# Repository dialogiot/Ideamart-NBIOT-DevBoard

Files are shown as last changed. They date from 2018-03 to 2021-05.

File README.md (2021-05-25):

### About the Board

The board is developed based on the [SIM7000C](http://www.simcomm2m.com/En/module/detail.aspx?id=167) and [SIM7000E](http://www.simcomm2m.com/En/module/detail.aspx?id=168) Modules as well as the Microcontroller ATMega 328 based on the most popular Arduino UNO PIN layout. Therefore this board is compatible with any shield that is compatible with the Arduino UNO

### Distribution
Any one can destribute or modify this deign. but originated souce should be published

### NB-IOT /GPS sample and SDK
[https://github.com/dialogiot/Dialog_NB-IOT_CAT-M](https://github.com/dialogiot/Dialog_NB-IOT_CAT-M)

#### Drivers

Download the [USB Drivers](https://github.com/botletics/SIM7000-LTE-Shield/wiki/SIM7000-USB-Drivers)
Note: Windows 10 users should use the Windows 8 Drivers



[View Image](https://idealab.ideamart.io/NBIOT-Dev-Board/img/features/board-diagram.jpg)

|No|PIN |Description|
|---|---|---|
| 1 | USB Port | Programing USB port for ATMEL Chip - PC driver may be required. Use Arduino USB cable or USB printer wire to connect with PC |
| 2 | FTDI | FTDI USB to Serial Converter FT232RL chip |
| 3 | LED2 | User programable LED |
| 4 | PIN Headers | Programable PIN headers to connect with micro controller. (Diagram 2 for more details) |
| 5 | Level Shifter | 1.8V to 5V voltage level shifter |
| 6 | SIM7000 | SIM7000 NB-IOT/eMTC/GSM/LTE Modem and GNSS Receiver |
| 7 | RF Antenna | RF mobile network antenna port for SIM7000 (u.fL) |
| 8 | GPS Antenna | GPS signal antenna port for SIM7000 (u.fL) |
| 9 | PPTC | PPTC resettable fuse for USB input over current protection (max 500mA) |
| 10 | DC Input | 2.1mm 7-12V DC power input |
| 11 | RESET | ATMEGA328P micro controller reset button |
| 12 | 3.3V Regulator | Lm1117 3.3V low dropout linear regulator (max 800ma)|
| 13 | 5V Regulator | LM1117 5V low dropout linear regulator (max 800mA) |
| 14 | PIN Headers | Programable PIN headers to connect with micro controller.(Diagram 2 for more details) |
| 15 | ATMEGA328P | ATMEGA328P micro controller |
| 16 | Power LED | Power indicator LED |
| 17 | ICSP Header | ICSP Header for Arduino programming |
| 18 | Modem Reset | SIM7000 modem hardware reset button |
| 19 | STAT LED | SIM7000 modem STAT LED indicator |
| 20 | Modem USB | SIM7000 modem USB port - firmware upgrade - Modem debug |
| 21 | PWR KEY | SIM7000 modem power key - Press 1.5sec to power up/down |
| 22 | Net Light | Power indicator LED |

## 2 What you Should know about the board

- ATMEGA328P µCU with FTDI USB to serial converter
- Same pinout as Arduino UNO
- Compatible with any Arduino UNO shield
- Programable with Arduino IDE
- NB-IoT/GSM/LTE/eMTC enabled SIM7000C/SIM7000E module onboard
- Separate USB interface for SIM7000 module
- GNSS (GPS,GLONASS and BeiDou/Compass, Galileo, QZSS)enabled 

> Separate USB interface can only be used for SIM7000 debug and firmware upgrades

- SIM7000C FDD-LTE B1/B3/B5/B8
- SIM7000E Tri-Band FDD-LTE B3/B8/B20/B28
- GSM/GPRS/EDGE 900/1800 MHz
- GNSS (GPS,GLONASS and BeiDou/Compass, Galileo, QZSS)
- LTE CAT-M1(eMTC) Uplink up to 375kbps, Downlink up to 300kbps
- NB-IoT Uplink up to 66kbps, Downlink up to 34kbps
- EDGE Class Uplink up to 236.8Kbps, Downlink up to 236.8Kbps
- GPRS Uplink up to 85.6Kbps, Downlink up to 85.6Kbps

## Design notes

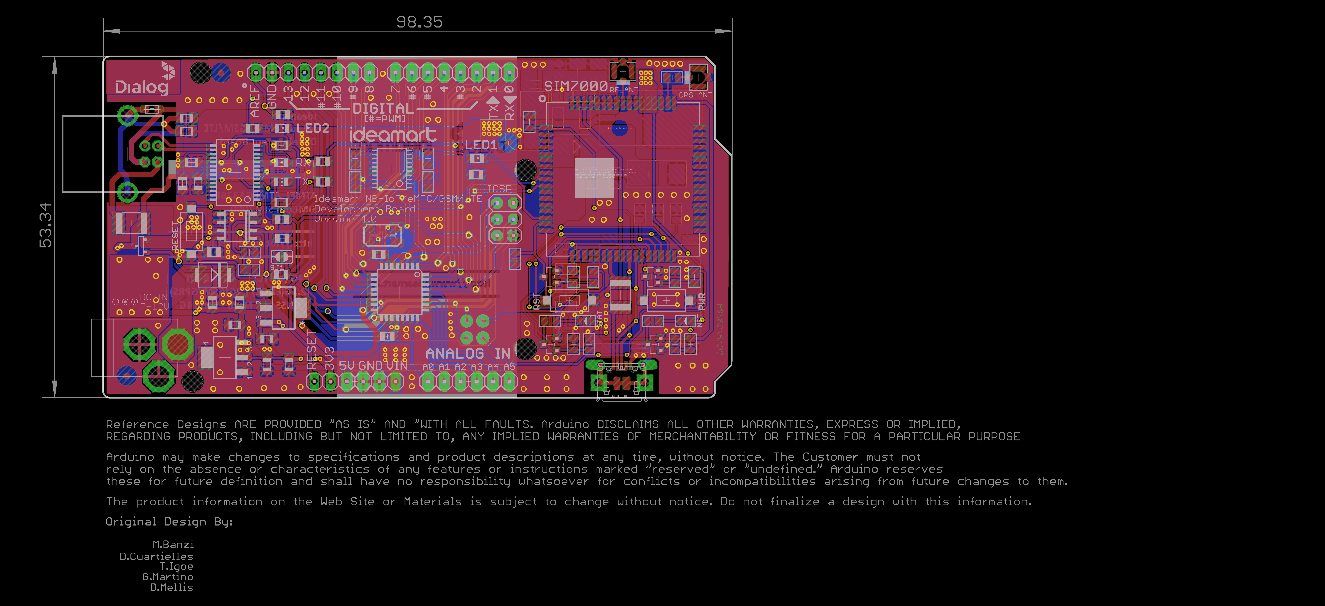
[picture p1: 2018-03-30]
Board-Images/Ideamart_NB-IoT_Dev_Board-Schematic-PCB_layout.png

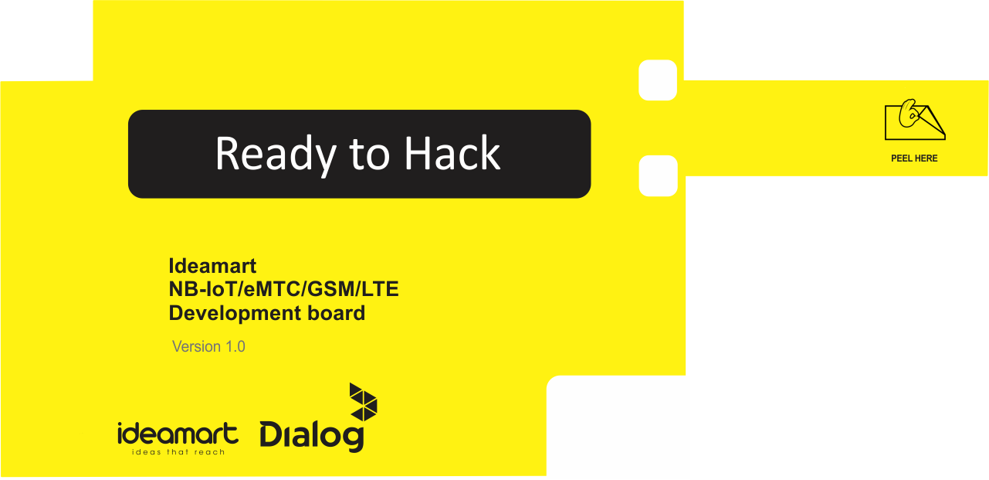
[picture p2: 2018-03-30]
Other-Images/Peel.png

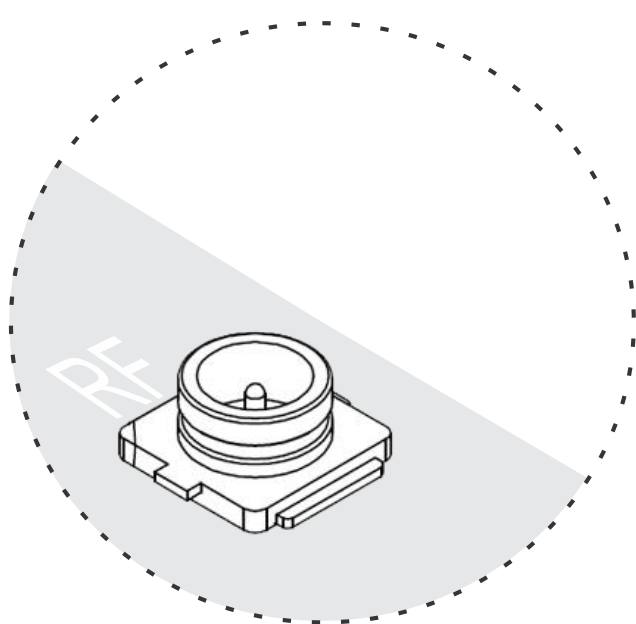
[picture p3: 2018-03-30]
Other-Images/Ant.png

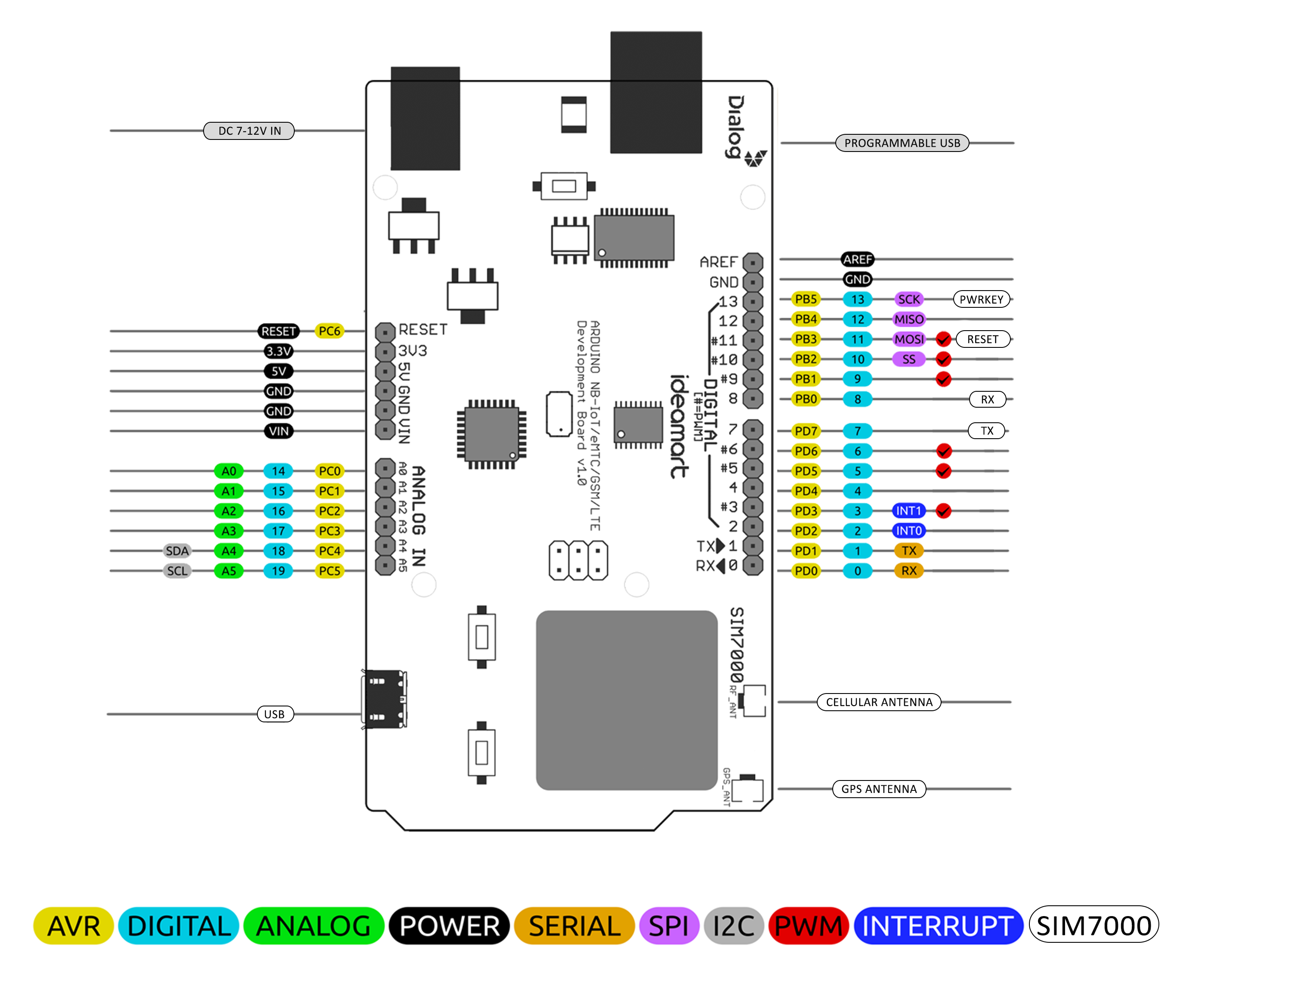
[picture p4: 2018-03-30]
Other-Images/PinOut.png

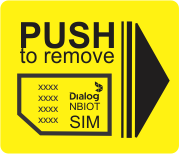
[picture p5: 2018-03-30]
Other-Images/Sim.png

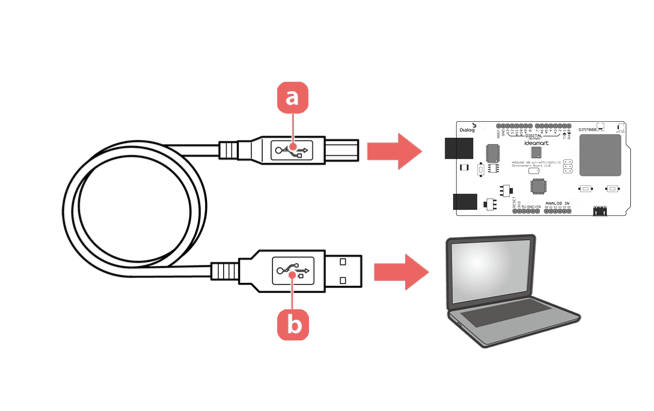
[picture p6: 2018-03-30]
Other-Images/Cable.png

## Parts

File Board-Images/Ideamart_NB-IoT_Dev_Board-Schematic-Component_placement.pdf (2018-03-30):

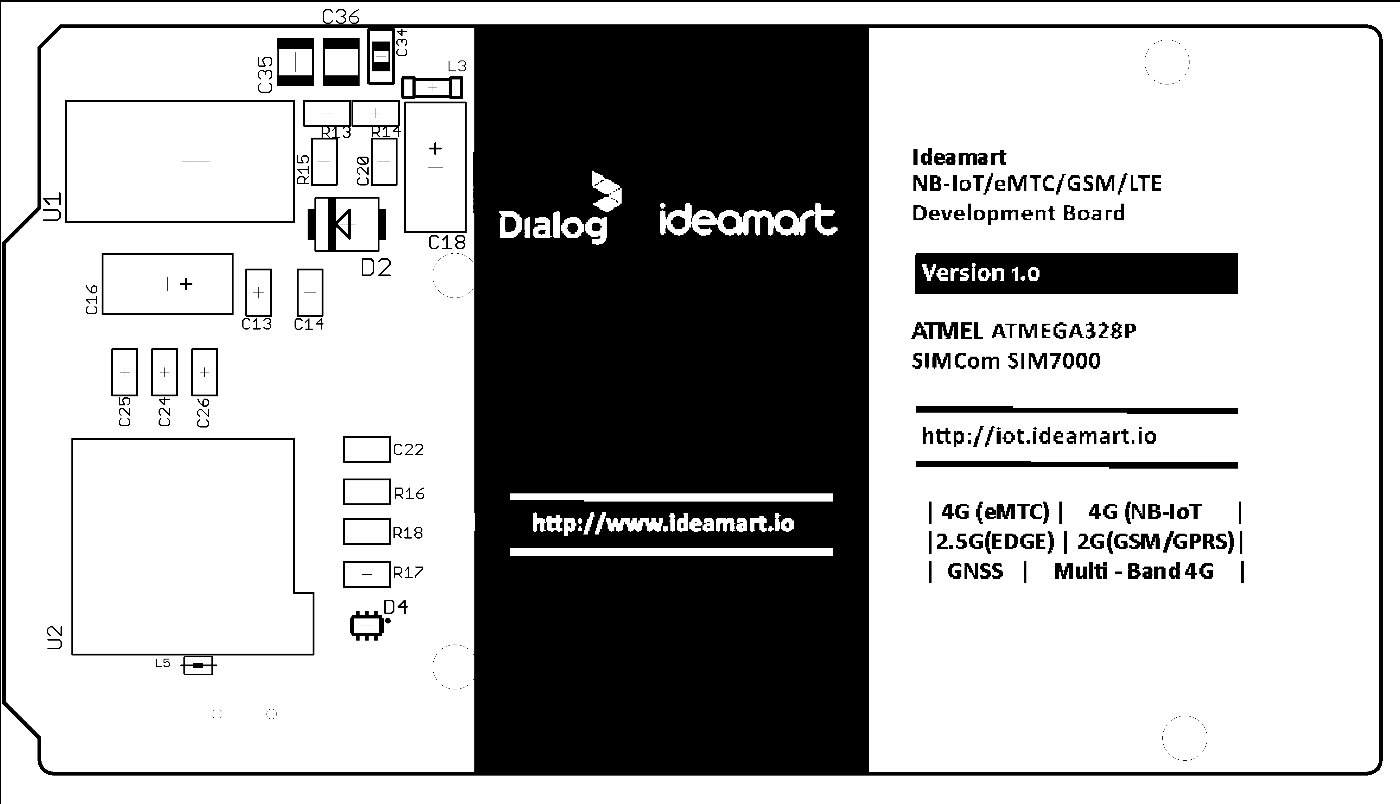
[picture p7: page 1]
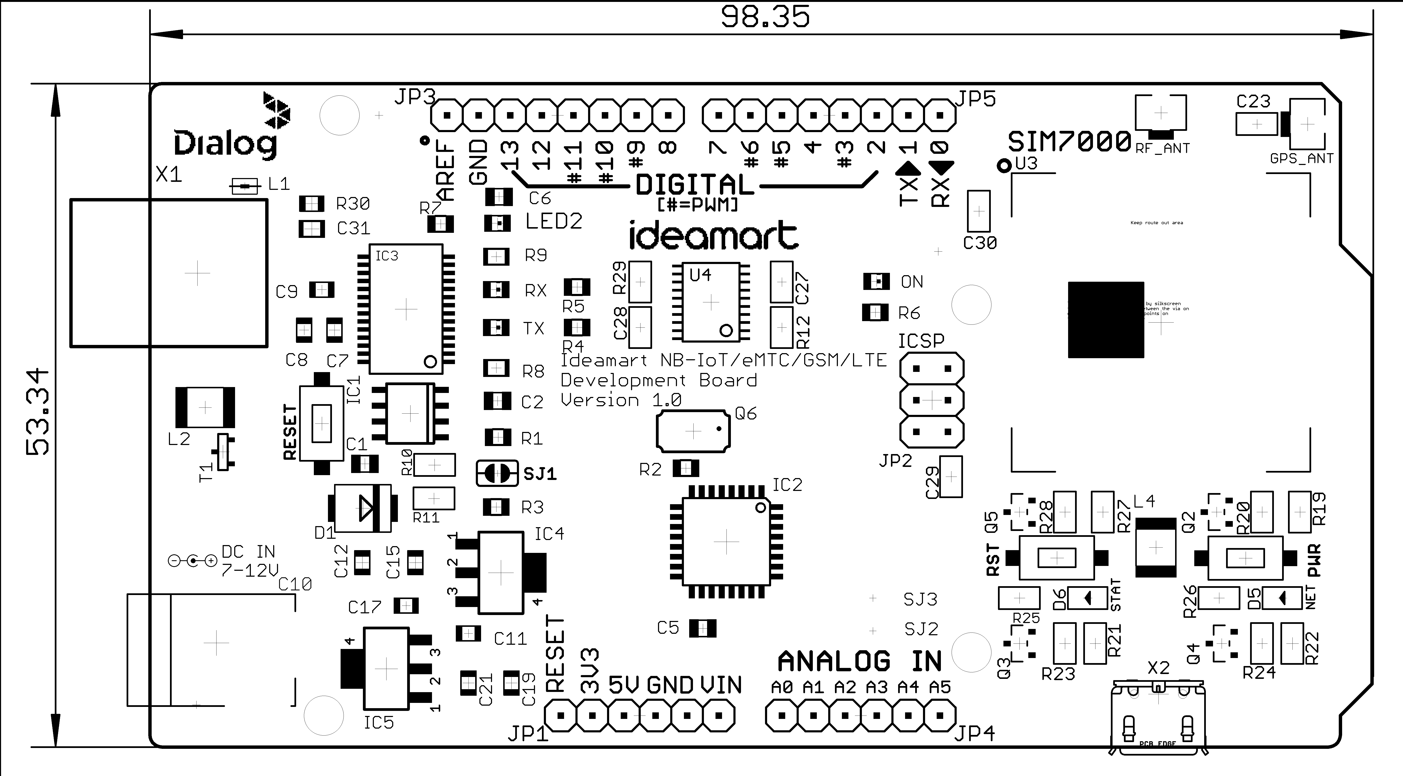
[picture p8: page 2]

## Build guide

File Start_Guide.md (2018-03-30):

## 1 Let's Start


- Insert Micro SIM to sim slot
- Connect GPS antenna to board

> NB-IOT / eMTC should available in your area

> Your SIM should allow to connect to NB-IOT network


- Connect your u.fL connector of GSM/LTE antenna to board
- Connect GPS antenna to board

## 2 Connect to the Computer

Connect Ideamart Board to the computer using USB cable



> You may need to install drivers for your computer.

> Download SDK and program with your faviorit Arduino IDE
SDK download from http://go.ideamart.io/NBIOTDevBoard

## 3 Board PIN out



[View Image](https://docs.iot.ideamart.io/images/nbiot/PinOut.png)

More Information/Sample and all you need info can find at
http://go.ideamart.io/NBIOTDevBoard

Dialog IOT Platform
http://portal.iot.ideamart.io

Dialog Smartlife app
http://go.ideamart.io/smartlife

### Microcontroller	ATmega328P

| | |
|-|-|
| Operating Voltage	| 5V |
| Input Voltage (recommended)	| 7-12V |
| Input Voltage (limit)	| 7-12V |
| Digital I/O Pins	| 14 (of which 6 provide PWM output) |
| PWM Digital I/O Pins	| 6 |
| Analog Input Pins	| 6 |
| DC Current per I/O Pin	| 20 mA |
| DC Current for 3.3V Pin	| 50 mA |
| Flash Memory	| 32 KB (ATmega328P) of which 0.5 KB used by bootloader |
| SRAM	| 2 KB (ATmega328P) |
| EEPROM	| 1 KB (ATmega328P) |
| Clock Speed	| 16 MHz |
| LED_BUILTIN	| 13 |
| Length	| 98.35 mm |
| Width	| 53.38 mm |

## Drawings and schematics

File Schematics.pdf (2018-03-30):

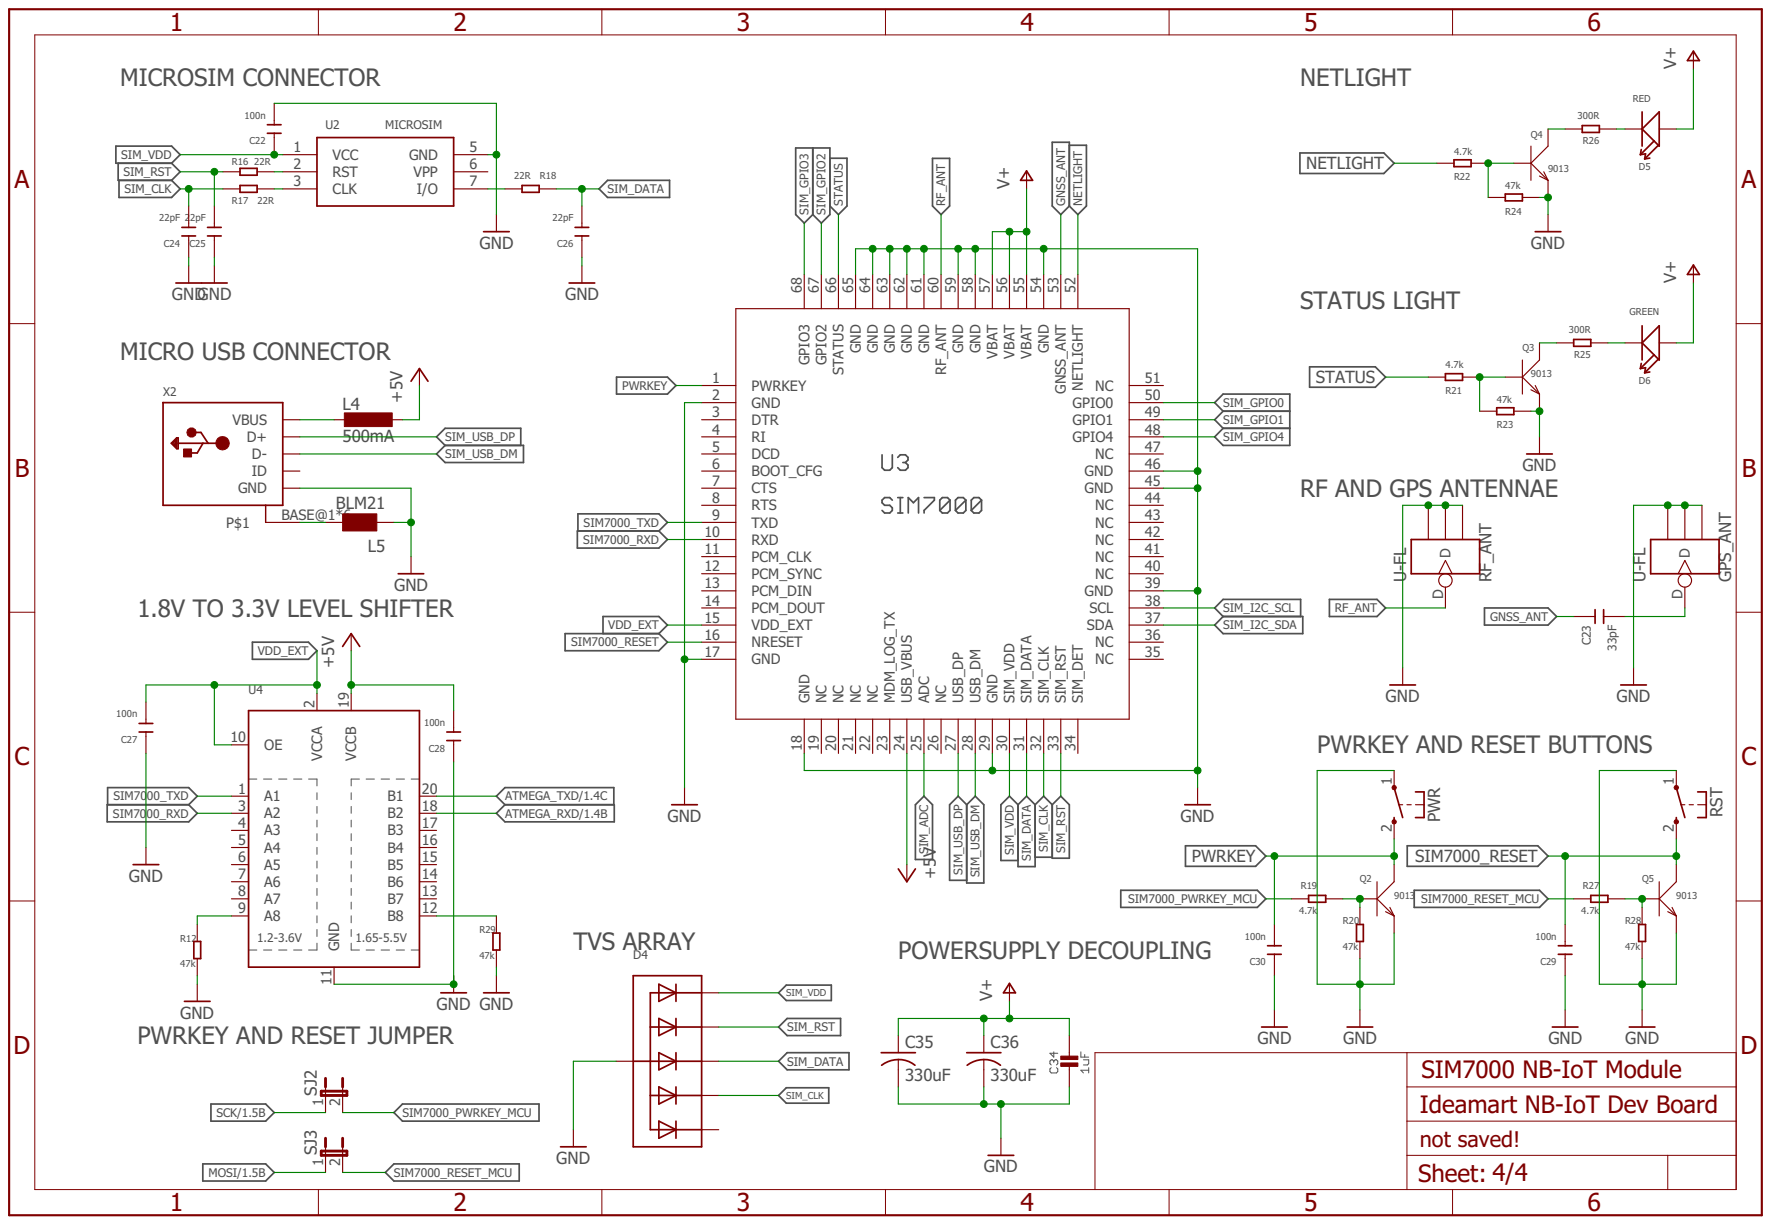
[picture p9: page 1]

RF AND GPS ANTENNAE

PWRKEY AND RESET BUTTONS

GND
PWRKEY AND RESET JUMPER

SIM7000 NB-IoT Module
Ideamart NB-IoT Dev Board

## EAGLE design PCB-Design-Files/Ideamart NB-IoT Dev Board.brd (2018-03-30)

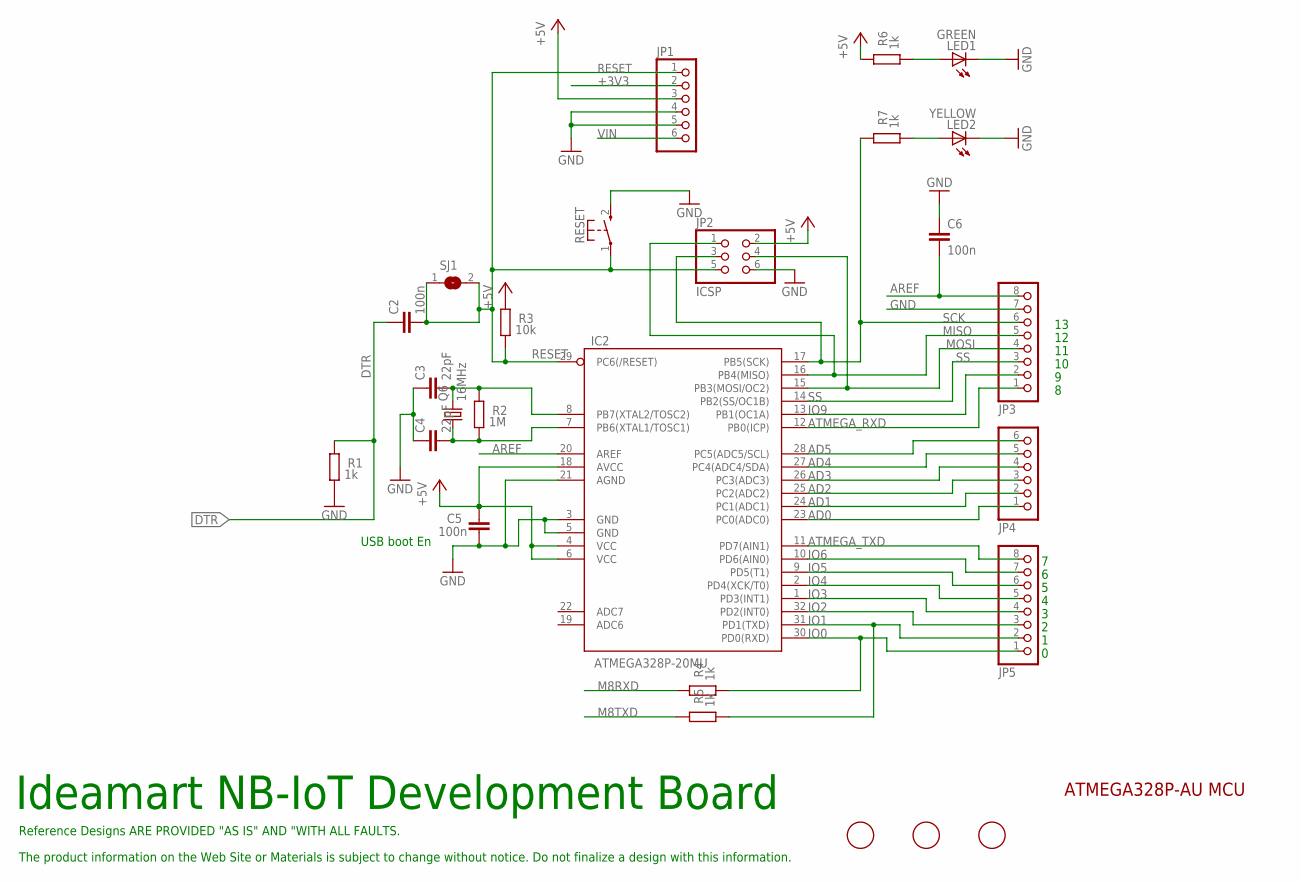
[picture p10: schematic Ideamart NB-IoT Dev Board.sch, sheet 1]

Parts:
C2, C5, C6: 100n; C0805
C3, C4: 22pF; C0805
IC2: ATMEGA328P-20MU; TQFP32-08
JP1, JP4: PINHD-1X6; 1X06
JP2: ICSP; 2X03
JP3, JP5: PINHD-1X8; 1X08
LED1: GREEN; CHIP-LED0805
LED2: YELLOW; CHIP-LED0805
M1, M2, M3: FIDUCIALMOUNT; FIDUCIA-MOUNT
Q6: 16MHz; CTS406
R1, R4, R5, R6, R7: 1k; R0805
R2: 1M; R0805
R3: 10k; R0805
RESET: KSS-2EG4430
SJ1: SJ

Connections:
+3V3: JP1.2; also elsewhere on the board
+5V: C5.2, IC2.4 (VCC), IC2.6 (VCC), IC2.18 (AVCC), JP1.3, JP2.2, R3.2, R6.2; also elsewhere on the board
AD0: IC2.23 (PC0(ADC0)), JP4.1
AD1: IC2.24 (PC1(ADC1)), JP4.2
AD2: IC2.25 (PC2(ADC2)), JP4.3
AD3: IC2.26 (PC3(ADC3)), JP4.4
AD4: IC2.27 (PC4(ADC4/SDA)), JP4.5
AD5: IC2.28 (PC5(ADC5/SCL)), JP4.6
AREF: C6.2, IC2.20 (AREF), JP3.8
ATMEGA_RXD: IC2.12 (PB0(ICP)), JP3.1; also elsewhere on the board
ATMEGA_TXD: IC2.11 (PD7(AIN1)), JP5.8; also elsewhere on the board
DTR: C2.1, R1.2; also elsewhere on the board
GND: C3.1, C4.1, C5.1, C6.1, IC2.3 (GND), IC2.5 (GND), IC2.21 (AGND), JP1.4, JP1.5, JP2.6, JP3.7, LED1.C, LED2.C, R1.1, RESET.2 (S); also elsewhere on the board
IO0: IC2.30 (PD0(RXD)), JP5.1, R4.1
IO1: IC2.31 (PD1(TXD)), JP5.2, R5.1
IO2: IC2.32 (PD2(INT0)), JP5.3
IO3: IC2.1 (PD3(INT1)), JP5.4
IO4: IC2.2 (PD4(XCK/T0)), JP5.5
IO5: IC2.9 (PD5(T1)), JP5.6
IO6: IC2.10 (PD6(AIN0)), JP5.7
IO9: IC2.13 (PB1(OC1A)), JP3.2
M8RXD: R4.2; also elsewhere on the board
M8TXD: R5.2; also elsewhere on the board
MISO: IC2.16 (PB4(MISO)), JP2.1, JP3.5
MOSI: IC2.15 (PB3(MOSI/OC2)), JP2.4, JP3.4; also elsewhere on the board
unnamed: LED2.A, R7.1
unnamed: LED1.A, R6.1
RESET: C2.2, IC2.29 (PC6(/RESET)), JP1.1, JP2.5, R3.1, RESET.1, SJ1.1, SJ1.2
SCK: IC2.17 (PB5(SCK)), JP2.3, JP3.6, R7.2; also elsewhere on the board
SS: IC2.14 (PB2(SS/OC1B)), JP3.3
VIN: JP1.6; also elsewhere on the board
XTAL1: C4.2, IC2.7 (PB6(XTAL1/TOSC1)), Q6.1, R2.1
XTAL2: C3.2, IC2.8 (PB7(XTAL2/TOSC2)), Q6.3 (2), R2.2

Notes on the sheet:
Ideamart NB-IoT Development Board
USB boot En
Reference Designs ARE PROVIDED "AS IS" AND "WITH ALL FAULTS.
The product information on the Web Site or Materials is subject to change without notice. Do not finalize a design with this information.
ATMEGA328P-AU MCU

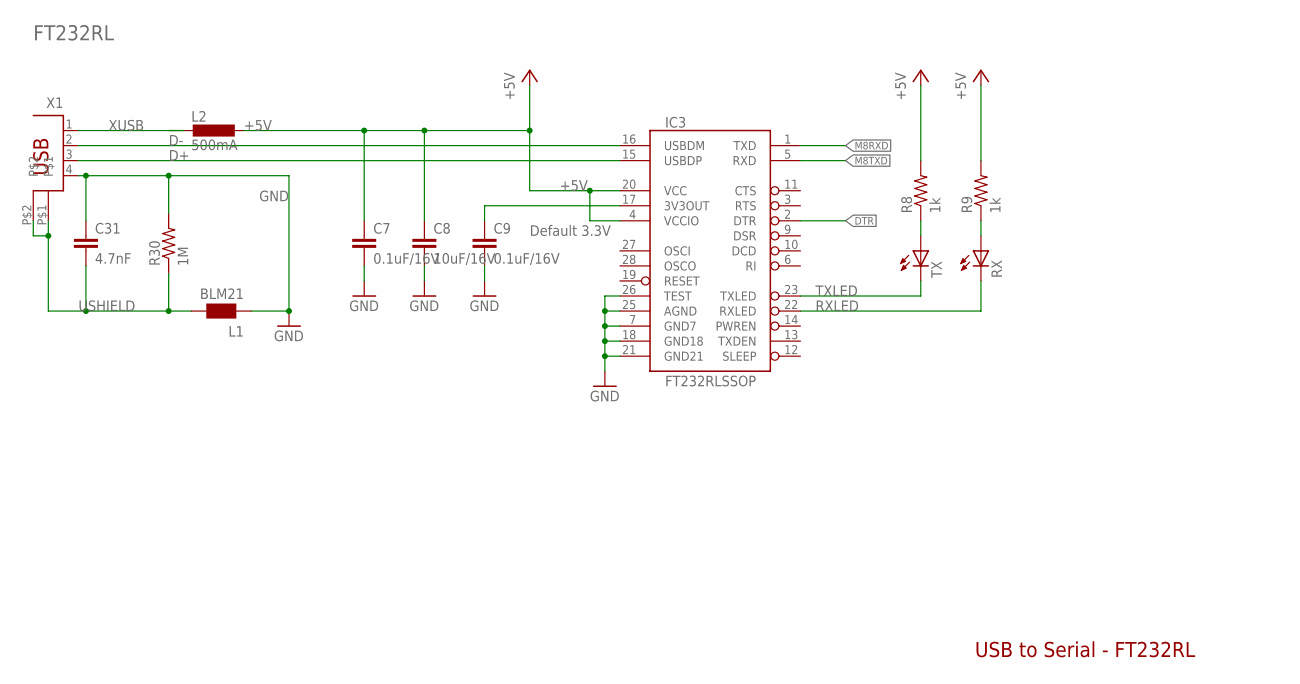
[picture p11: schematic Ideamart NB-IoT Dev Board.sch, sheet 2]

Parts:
C7, C9: 0.1uF/16V; C0805K
C8: 10uF/16V; C0805K
C31: 4.7nF; C0805K
IC3: FT232RLSSOP; SSOP28DB
L1: BLM21; 0805
L2: 500mA; L1812
R8, R9: 1k; M0805
R30: 1M; M0805
RX: LEDCHIP-LED0805; CHIP-LED0805
TX: LEDCHIP-LED0805; CHIP-LED0805
X1: PN61729

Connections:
+5V: C7.1, C8.1, IC3.4 (VCCIO), IC3.20 (VCC), L2.1, R8.2, R9.2; also elsewhere on the board
D+: IC3.15 (USBDP), X1.3
D-: IC3.16 (USBDM), X1.2
DTR: IC3.2 (DTR); also elsewhere on the board
GND: C7.2, C8.2, C9.2, C31.1, IC3.7 (GND7), IC3.18 (GND18), IC3.21 (GND21), IC3.25 (AGND), IC3.26 (TEST), L1.1, R30.2, X1.4; also elsewhere on the board
M8RXD: IC3.1 (TXD); also elsewhere on the board
M8TXD: IC3.5 (RXD); also elsewhere on the board
unnamed: C9.1, IC3.17 (3V3OUT)
unnamed: R8.1, TX.A
unnamed: R9.1, RX.A
RXLED: IC3.22 (RXLED), RX.C
TXLED: IC3.23 (TXLED), TX.C
USHIELD: C31.2, L1.2, R30.1, X1.P$1, X1.P$2
XUSB: L2.2, X1.1

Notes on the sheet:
Default 3.3V
USB to Serial - FT232RL
FT232RL

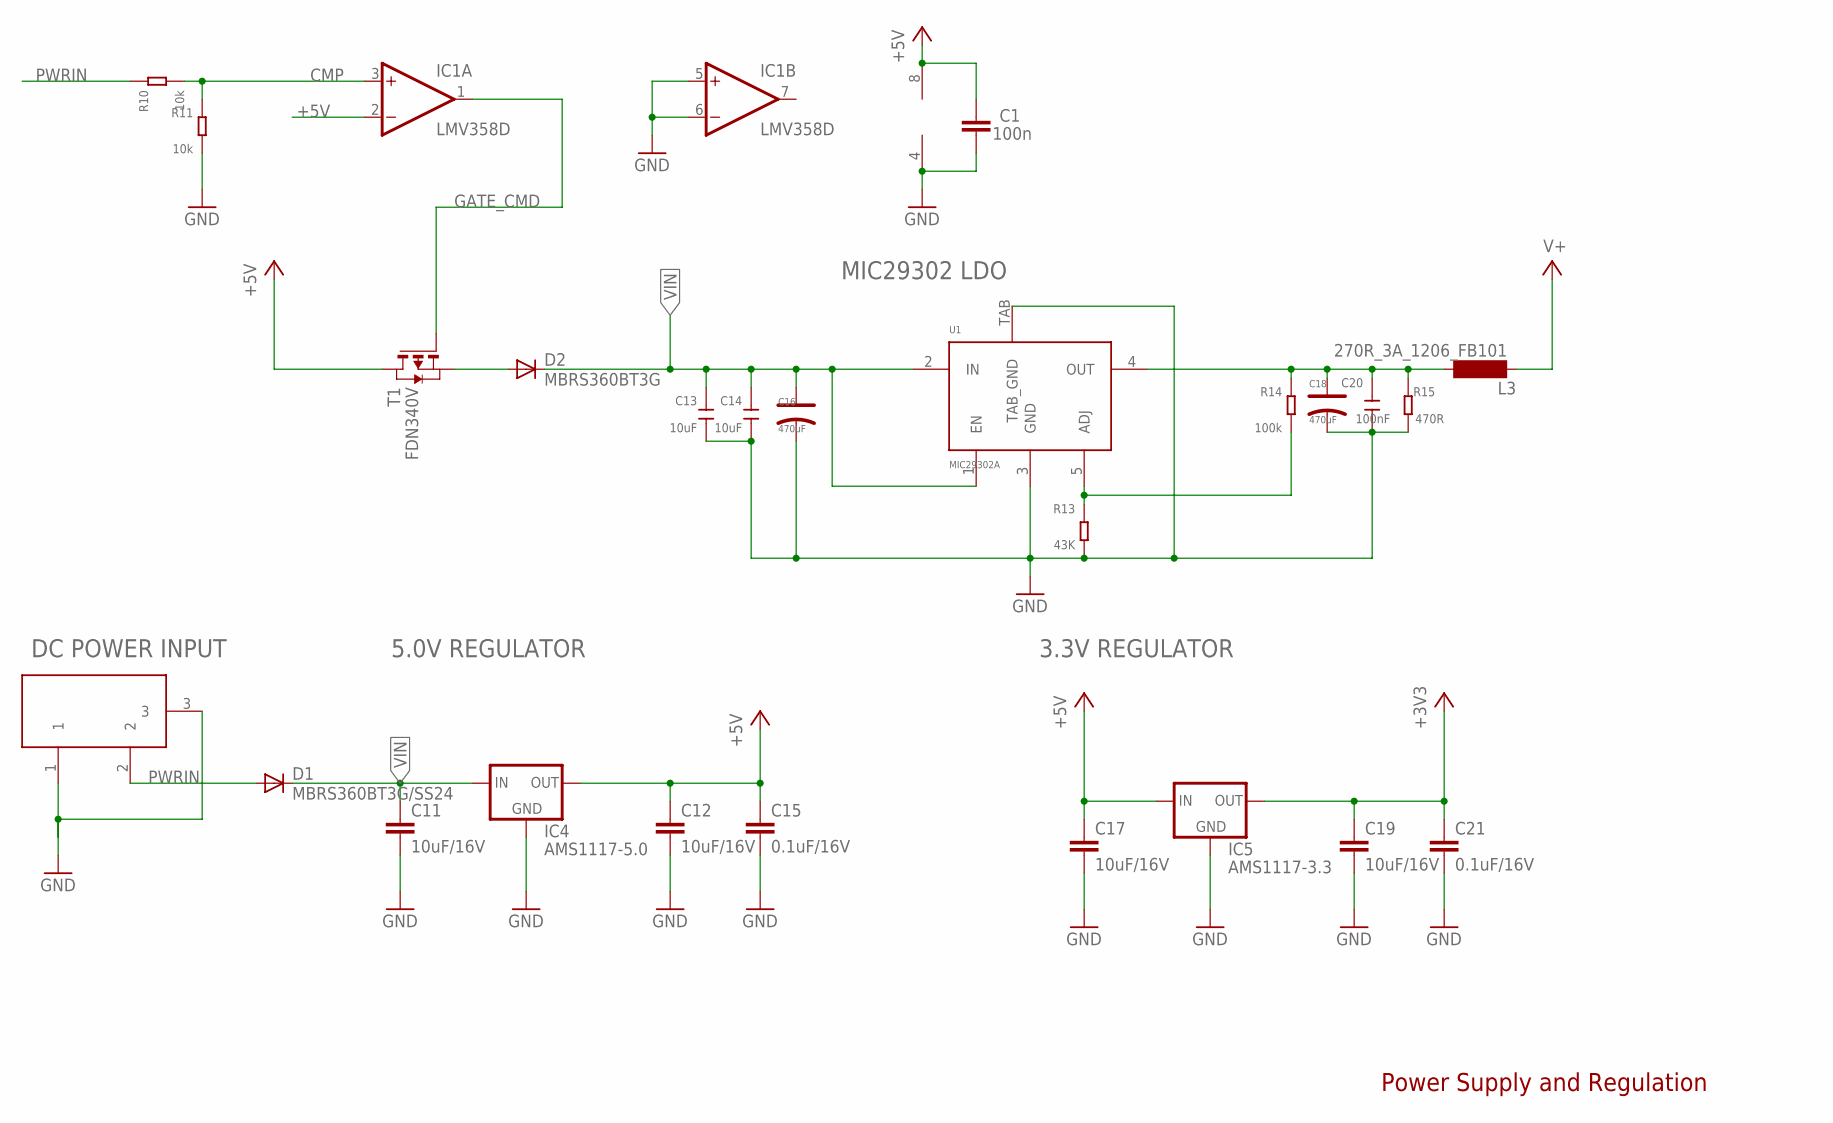
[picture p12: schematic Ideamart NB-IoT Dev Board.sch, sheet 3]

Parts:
C1: 100n; C0805
C10: DC21MMX; DC-21MM
C11, C12, C17, C19: 10uF/16V; C0805K
C13, C14: 10uF; 0805
C15, C21: 0.1uF/16V; C0805K
C16, C18: 470uF; AVX_D
C20: 100nF; 0805
D1: MBRS360BT3G/SS24; SMB
D2: MBRS360BT3G; SMB
IC1: LMV358D; SO08
IC4: AMS1117-5.0; SOT223
IC5: AMS1117-3.3; SOT223
L3: 270R_3A_1206_FB101; SM-1206
R10, R11: 10k; 0805
R13: 43K; 0805
R14: 100k; 0805
R15: 470R; 0805
T1: FDN340V; SOT-23
U1: MIC29302A; TO-263A

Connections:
+3V3: C19.1, C21.1, IC5.2 (OUT); also elsewhere on the board
+5V: C1.2, C12.1, C15.1, C17.1, IC1.2 (-IN), IC1.8 (V+), IC4.2 (OUT), IC5.3 (IN), T1.1 (D); also elsewhere on the board
CMP: IC1.3 (+IN), R10.1, R11.2
GATE_CMD: IC1.1 (OUT), T1.3 (G)
GND: C1.1, C10.1, C10.3, C11.2, C12.2, C13.1, C14.1, C15.2, C16.-, C17.2, C18.-, C19.2, C20.1, C21.2, IC1.4 (V-), IC1.5 (+IN), IC1.6 (-IN), IC4.1 (GND), IC5.1 (GND), R11.1, R13.1, R15.1, U1.3 (GND), U1.TAB (TAB_GND); also elsewhere on the board
unnamed: R13.2, R14.1, U1.5 (ADJ)
unnamed: D2.A, T1.2 (S)
PWRIN: C10.2, D1.A, R10.2
V+: L3.1; also elsewhere on the board
VIN: C11.1, C13.2, C14.2, C16.+, D1.C, D2.C, IC4.3 (IN), U1.1 (EN), U1.2 (IN); also elsewhere on the board
VOUT: C18.+, C20.2, L3.2, R14.2, R15.2, U1.4 (OUT)

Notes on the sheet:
DC POWER INPUT
Power Supply and Regulation
3.3V REGULATOR
MIC29302 LDO
5.0V REGULATOR

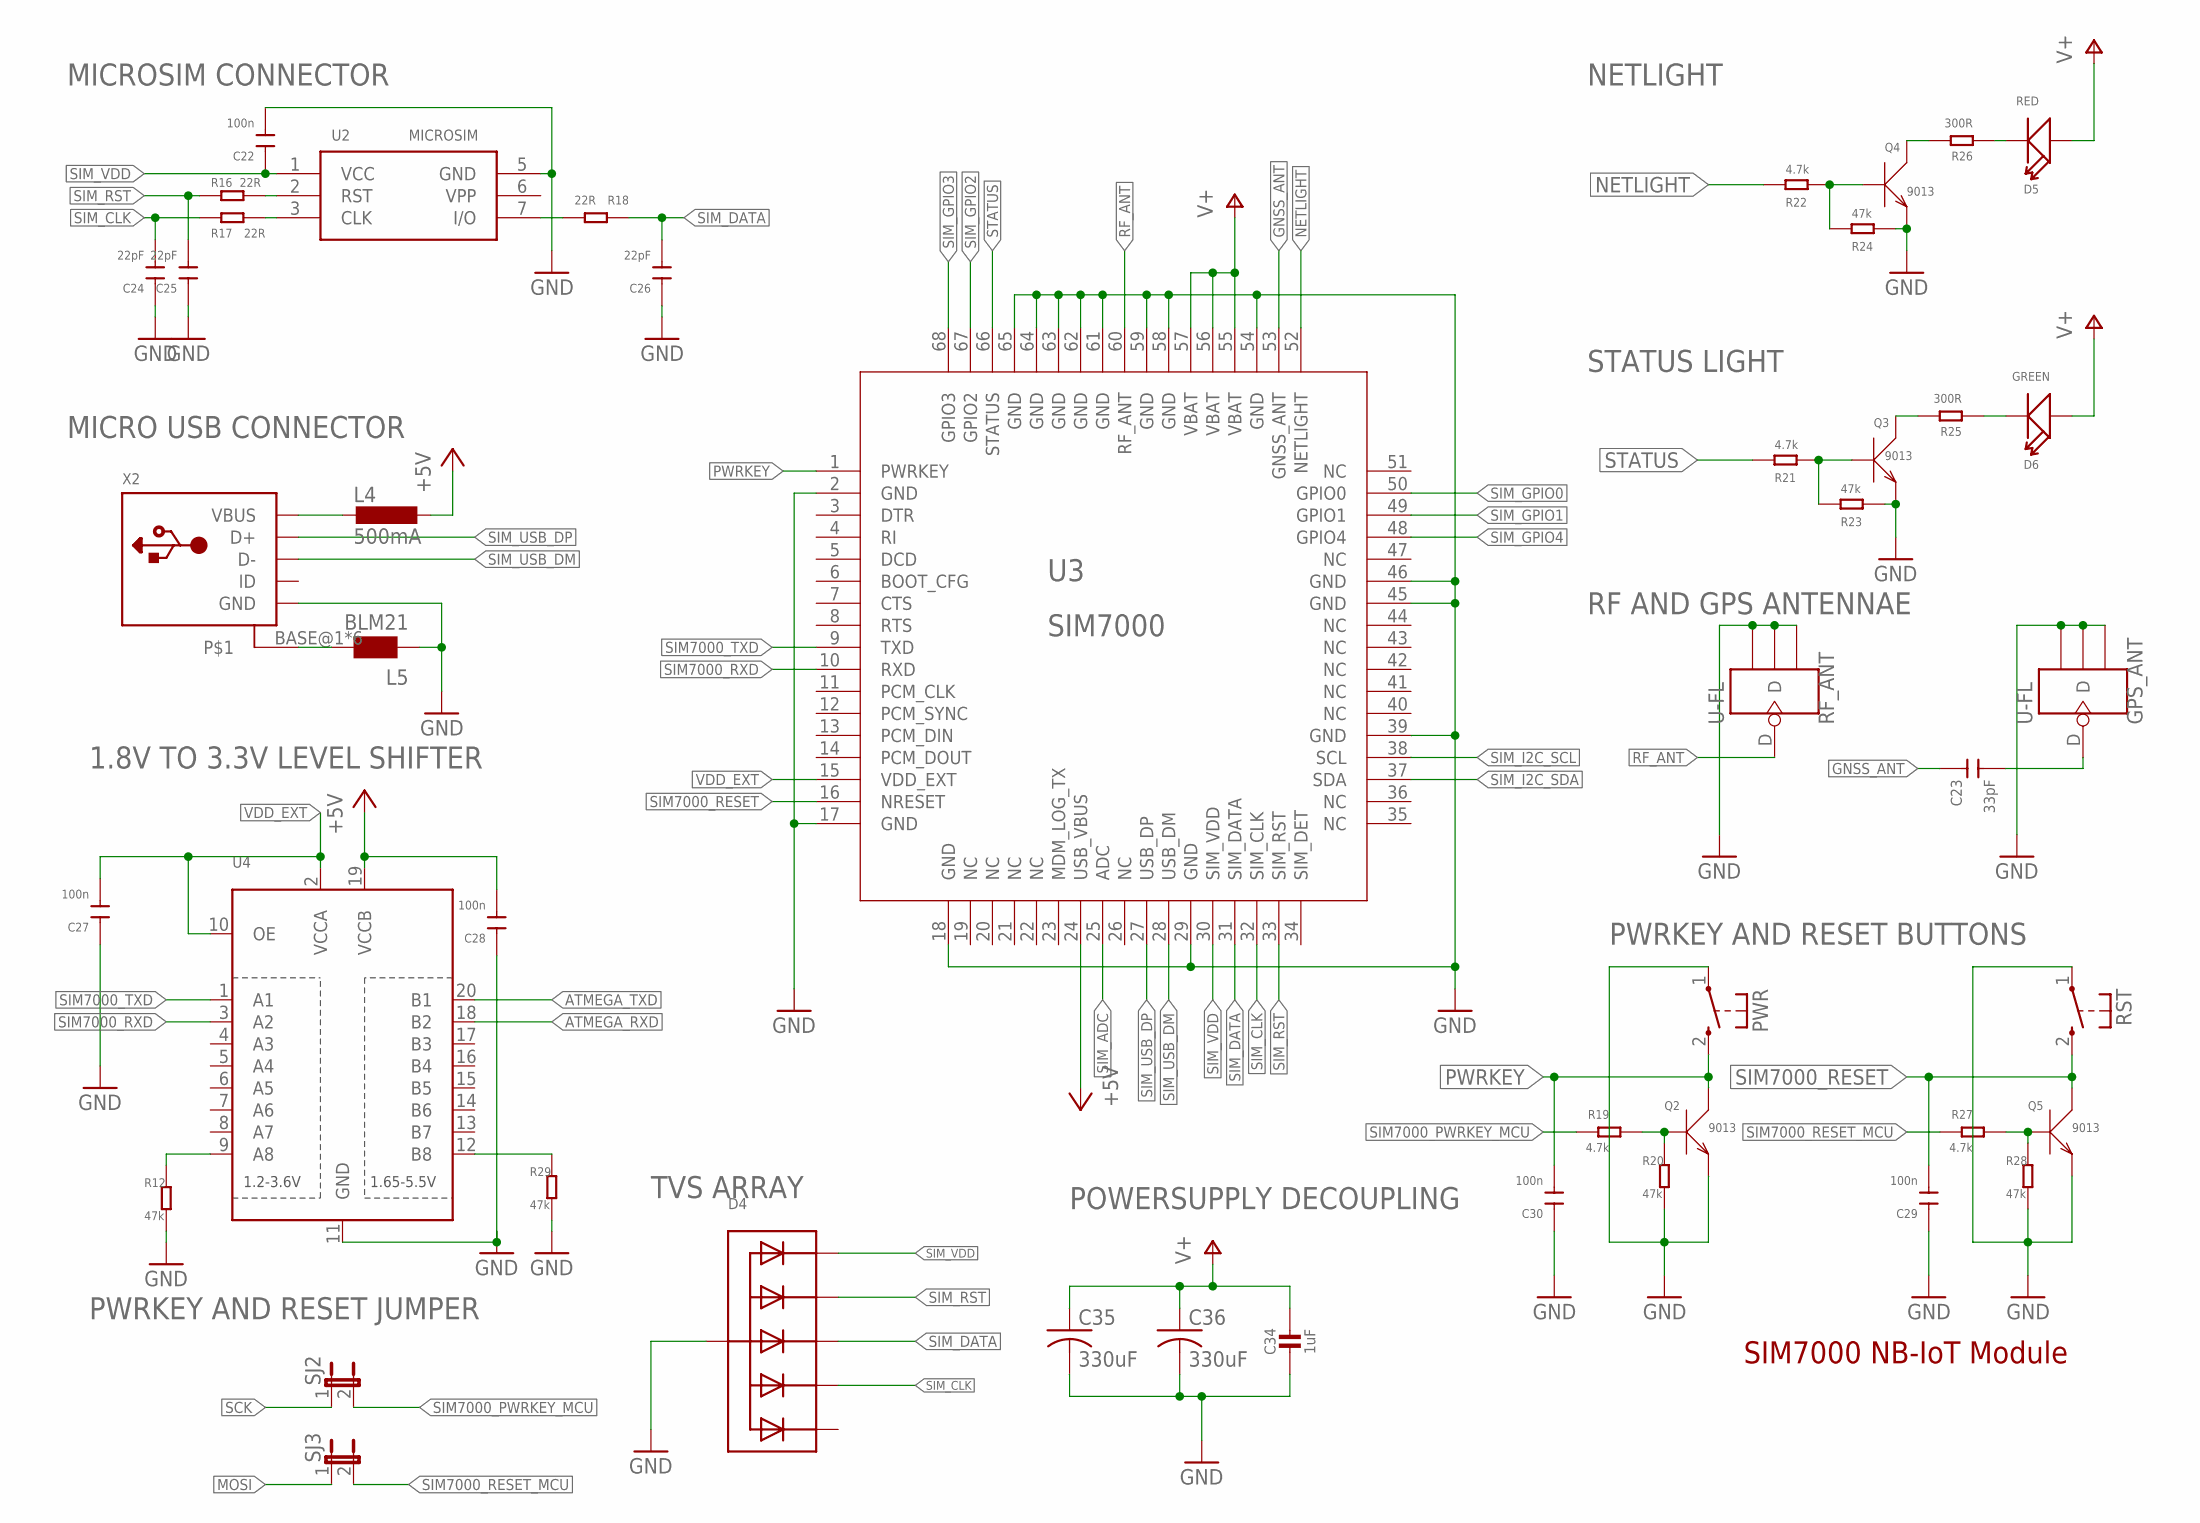
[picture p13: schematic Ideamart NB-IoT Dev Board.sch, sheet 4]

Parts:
C22, C27, C28, C29, C30: 100n; 0805
C23: 33pF; 0805
C24, C25, C26: 22pF; 0805
C34: 1uF; _0805
C35, C36: 330uF; C1210
D4: TVSARRAY_5LANE; SOT363
D5: RED; LED-0805
D6: GREEN; LED-0805
GPS_ANT: U-FL; 4P-U-FL
L4: 500mA; L1812
L5: BLM21; 0805
PWR: KSS-2EG4430
Q2, Q3, Q4, Q5: 9013; SOT23
R12, R20, R23, R24, R28, R29: 47k; 0805
R16, R17, R18: 22R; 0805
R19, R21, R22, R27: 4.7k; 0805
R25, R26: 300R; 0805
RF_ANT: U-FL; 4P-U-FL
RST: KSS-2EG4430
SJ2, SJ3: SPARKFUN-PASSIVES_JUMPER-PTH-2-NC; SPARKFUN-PASSIVES_PTH-JUMPER-NC_BOTTOM_NO_SILK
U2: MICROSIM
U3: SIM7000
U4: TXB0108PWR; TSSOP20
X2: USB_MICRO_20329_V2; 4UCONN_20329_V2

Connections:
+5V: C28.2, L4.1, U3.24 (USB_VBUS), U4.19 (VCCB); also elsewhere on the board
ATMEGA_RXD: U4.18 (B2); also elsewhere on the board
ATMEGA_TXD: U4.20 (B1); also elsewhere on the board
GND: C22.2, C24.1, C25.1, C26.1, C27.1, C28.1, C29.1, C30.1, C34.2, C35.2, C36.2, D4.2 (A), GPS_ANT.GND1, GPS_ANT.GND2, GPS_ANT.GND3, L5.1, PWR.1, Q2.2 (E), Q3.2 (E), Q4.2 (E), Q5.2 (E), R12.2, R20.2, R23.2, R24.2, R28.2, R29.2, RF_ANT.GND1, RF_ANT.GND2, RF_ANT.GND3, RST.1, U2.5 (GND), U3.2 (GND), U3.17 (GND), U3.18 (GND), U3.29 (GND), U3.39 (GND), U3.45 (GND), U3.46 (GND), U3.54 (GND), U3.58 (GND), U3.59 (GND), U3.61 (GND), U3.62 (GND), U3.63 (GND), U3.64 (GND), U3.65 (GND), U4.11 (GND), X2.GND; also elsewhere on the board
GNSS_ANT: C23.2, U3.53 (GNSS_ANT)
MOSI: SJ3.1; also elsewhere on the board
unnamed: Q3.3 (C), R25.2
unnamed: D6.-, R25.1
unnamed: Q3.1 (B), R21.2, R23.1
unnamed: R18.2, U2.7 (I/O)
unnamed: R17.1, U2.3 (CLK)
unnamed: R16.1, U2.2 (RST)
unnamed: Q5.1 (B), R27.2, R28.1
unnamed: L4.2, X2.VBUS
unnamed: Q4.3 (C), R26.2
unnamed: D5.-, R26.1
unnamed: Q4.1 (B), R22.2, R24.1
unnamed: C23.1, GPS_ANT.D
unnamed: R12.1, U4.9 (A8)
unnamed: R29.1, U4.12 (B8)
unnamed: L5.2, X2.BASE@1, X2.BASE@2, X2.SPRT@1, X2.SPRT@2, X2.SPRT@3, X2.SPRT@4
unnamed: Q2.1 (B), R19.2, R20.1
NETLIGHT: R22.1, U3.52 (NETLIGHT)
PWRKEY: C30.2, PWR.2 (S), Q2.3 (C), U3.1 (PWRKEY)
RF_ANT: RF_ANT.D, U3.60 (RF_ANT)
SCK: SJ2.1; also elsewhere on the board
SIM7000_PWRKEY_MCU: R19.1, SJ2.2
SIM7000_RESET: C29.2, Q5.3 (C), RST.2 (S), U3.16 (NRESET)
SIM7000_RESET_MCU: R27.1, SJ3.2
SIM7000_RXD: U3.10 (RXD), U4.3 (A2)
SIM7000_TXD: U3.9 (TXD), U4.1 (A1)
SIM_ADC: U3.25 (ADC)
SIM_CLK: C24.2, D4.5 (C4), R17.2, U3.32 (SIM_CLK)
SIM_DATA: C26.2, D4.4 (C3), R18.1, U3.31 (SIM_DATA)
SIM_GPIO0: U3.50 (GPIO0)
SIM_GPIO1: U3.49 (GPIO1)
SIM_GPIO2: U3.67 (GPIO2)
SIM_GPIO3: U3.68 (GPIO3)
SIM_GPIO4: U3.48 (GPIO4)
SIM_I2C_SCL: U3.38 (SCL)
SIM_I2C_SDA: U3.37 (SDA)
SIM_RST: C25.2, D4.3 (C2), R16.2, U3.33 (SIM_RST)
SIM_USB_DM: U3.28 (USB_DM), X2.D-
SIM_USB_DP: U3.27 (USB_DP), X2.D+
SIM_VDD: C22.1, D4.1 (C1), U2.1 (VCC), U3.30 (SIM_VDD)
STATUS: R21.1, U3.66 (STATUS)
V+: C34.1, C35.1, C36.1, D5.+, D6.+, U3.55 (VBAT), U3.56 (VBAT), U3.57 (VBAT); also elsewhere on the board
VDD_EXT: C27.2, U3.15 (VDD_EXT), U4.2 (VCCA), U4.10 (OE)

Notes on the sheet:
TVS ARRAY
MICROSIM CONNECTOR
SIM7000 NB-IoT Module
MICRO USB CONNECTOR
NETLIGHT
STATUS LIGHT
RF AND GPS ANTENNAE
PWRKEY AND RESET BUTTONS
PWRKEY AND RESET JUMPER
1.8V TO 3.3V LEVEL SHIFTER
POWERSUPPLY DECOUPLING

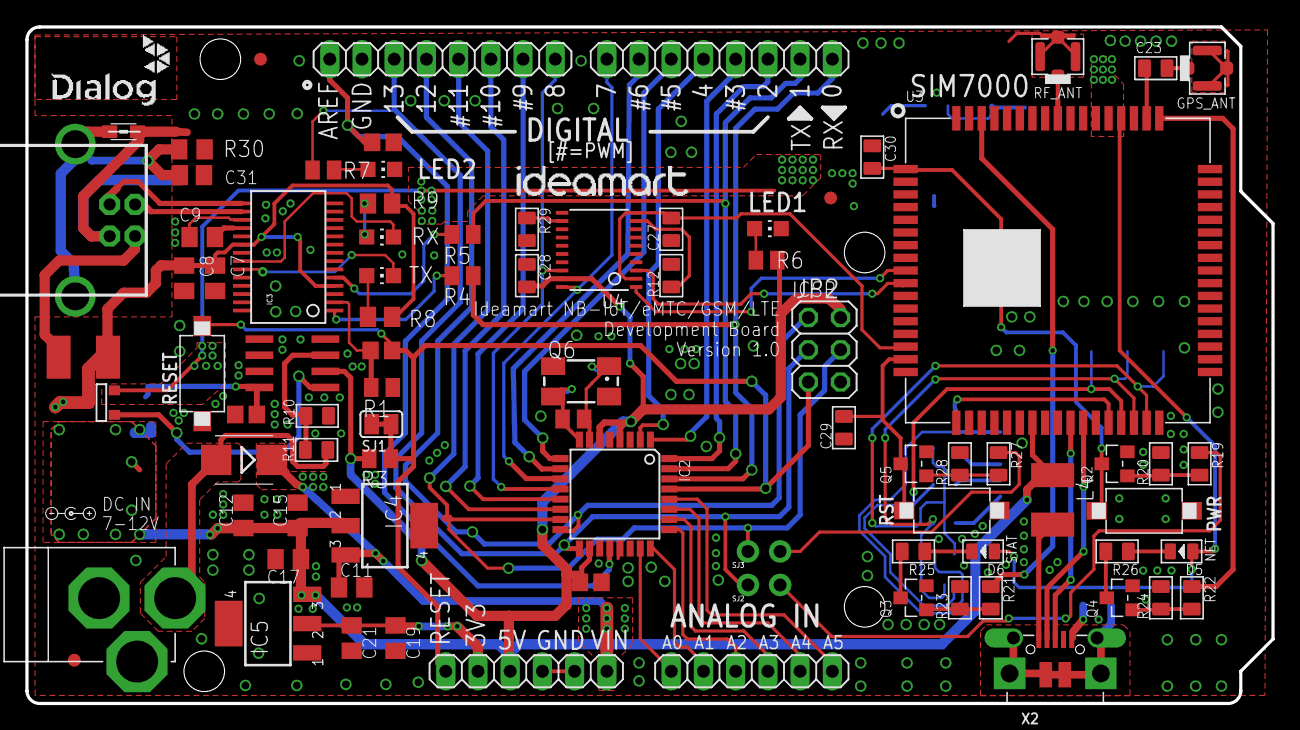
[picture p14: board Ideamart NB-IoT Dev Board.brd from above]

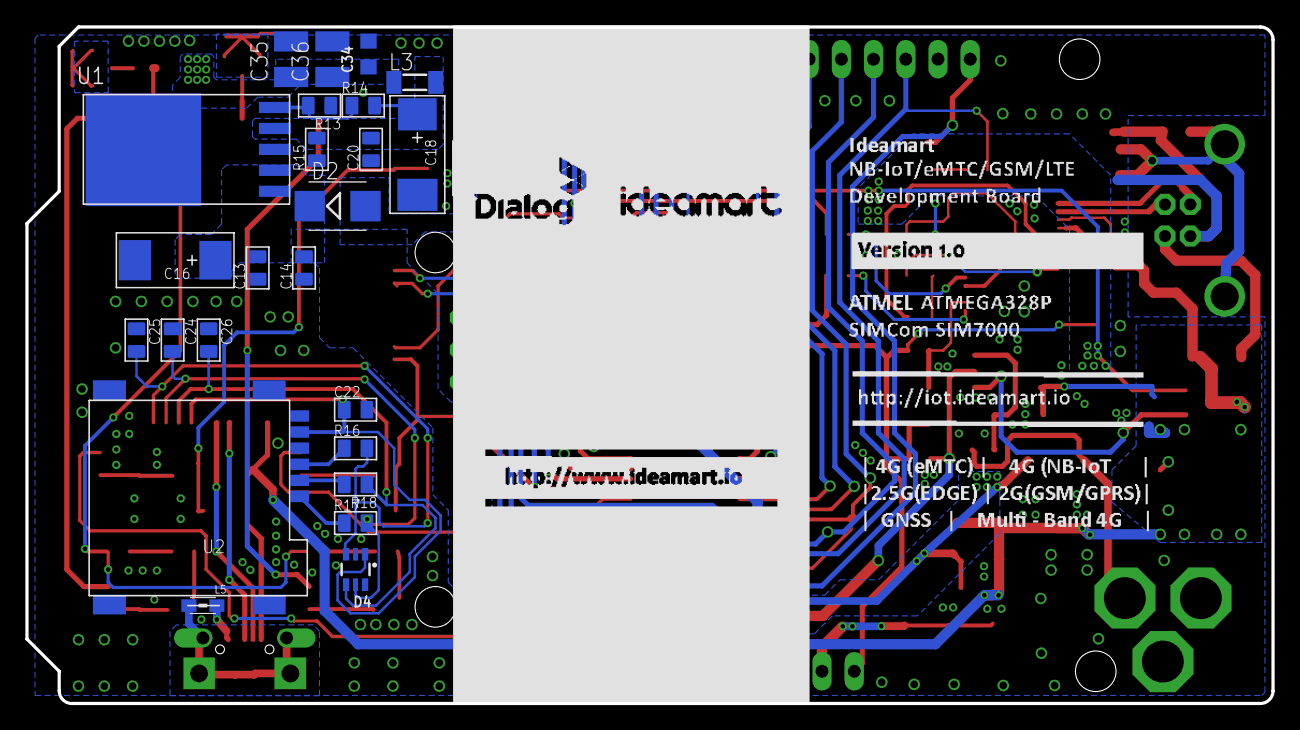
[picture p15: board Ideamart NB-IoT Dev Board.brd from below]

Board: 2 copper layers, 98.2 x 53.3 mm, 111 parts (26 on the bottom side), 82 nets.
